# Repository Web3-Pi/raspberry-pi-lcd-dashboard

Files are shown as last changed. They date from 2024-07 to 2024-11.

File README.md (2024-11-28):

# LCD Dashboard for Raspberry Pi SBCs

<p align="center">
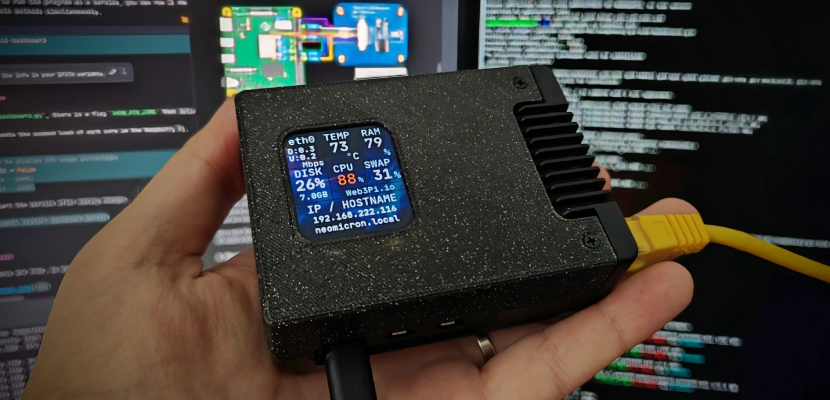
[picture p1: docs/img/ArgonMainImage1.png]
  
</p>

<p align="left">


</p>

***Unique hardware dashboard for Raspberry Pi 4 and Raspberry Pi 5 with 3D model for Argon Neo 5 enclosure*** 

***This repository is part of the [Web3Pi](https://www.web3pi.io) initiative, which enables the automated deployment of a full Ethereum node on a Raspberry Pi.***

This project allows you to install a color LCD display in the Argon Neo 5 case and display the following system parameters:

- CPU Usage
- CPU Temperature
- RAM Usage
- SWAP Memory Usage
- Storage Usage
- IP / Hostname
- Network Traffic (eth0/WiFi)

We have designed our own 3D model of the enclosure cover with a space for the display. The assembly is simple, using snap-fits, with no tools required. The models are open-source, so anyone can print them on a 3D printer. The source code is also open-source, allowing users to add new functionalities, customize it to their needs, or add support for new displays.

## Disclaimer

Raspberry Pi is a trademark of Raspberry Pi Ltd. The use of this trademark here is solely for descriptive purposes. I am not affiliated with Raspberry Pi Ltd. I derive no financial benefit from this content.

## Requirements

- Python >= 3.9
- Run on Raspberry Pi 4 and 5
- Raspberry Pi OS or Ubuntu
- [SPI interface enabled](docs/EnableSPI.md)
- 1.69" LCD display with ST7789V2 Driver
  - Waveshare 24382 - [product page](https://www.waveshare.com/1.69inch-lcd-module.htm)
  - Seeed Studio 104990802 - [product page](https://www.seeedstudio.com/1-69inch-240-280-Resolution-IPS-LCD-Display-Module-p-5755.html)
- (Optional) 3D printed model of Argon Neo 5 cover
- (Optional) Argon Neo 5 enclosure

## Assembly

### 1. Connect wires
Connect the display to the Raspberry Pi according to the diagram below.  
The colors of the cables may vary depending on the supplier and batch. Focus on the function and pin number, not the color.

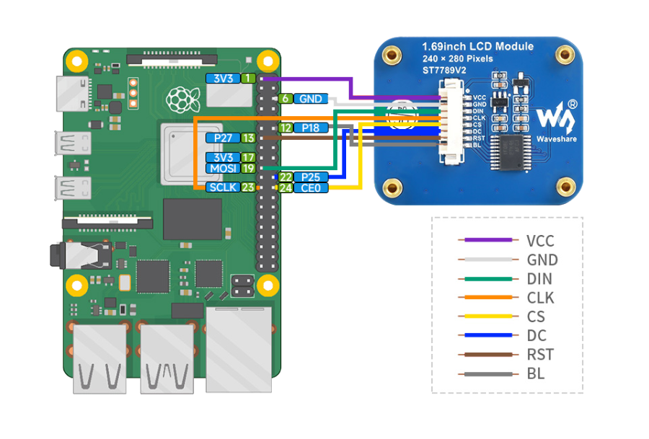
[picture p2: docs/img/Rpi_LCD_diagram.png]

Diagram is valid for Raspberry Pi 4 and Pi 5

If on Raspberry Pi 5 your LCD backlight is flickering connect `BL` to `3.3V PIN 17`

### 2. Mount display module

Mount the display in the printed enclosure cover. The display is held in place by four clips. Make sure all 3D printing support residues are removed and the surface to which the display adheres is flat. Install the display by sliding one side under the clips first, then pressing the other side down. Do not use excessive force to avoid damaging the display. The display should fit in easily.

Since each 3D printer may be calibrated differently, it may be necessary to adjust the scale of the 3D model in the slicer software before printing. Our prints are done on [Original Prusa i3 MK3S+](https://www.prusa3d.com/pl/produkt/drukarka-3d-original-prusa-i3-mk3s-3/).

### 3. Mount enclosure cover

Mount the enclosure cover and secure it with two screws. Make sure to arrange the cables inside the enclosure so they do not obstruct the fan and minimize interference with cooling.

## Installation

To enable the display, the SPI interface must be enabled.  
To do this, execute the following command and then reboot the device:

```shell
sudo sed -i '/^#dtparam=spi=on/s/^#//' /boot/firmware/config.txt
sudo reboot
```

Download the repository.

```shell
sudo apt-get -y install git
git clone https://github.com/Web3-Pi/raspberry-pi-lcd-dashboard.git
```

Then, you can run the program as a service. The program will start automatically with the system startup.  
Alternatively, you can run it once. The program will stop when you close the console.

### Run as a service - (recommended)   

```shell
cd raspberry-pi-lcd-dashboard
chmod +x *.sh
sudo ./create_service.sh
```

To **stop** the program, execute `sudo systemctl stop dashboard.service`

To **uninstall** the service, execute `sudo ./remove_service.sh`

### or run one time

If you do not want to run the program as a service, you can run it once.   
Note: Do not use both methods simultaneously.

```shell
cd raspberry-pi-lcd-dashboard
chmod +x *.sh
sudo ./run.sh
```
To stop the program, press Ctrl+C.

## Customisation

In the file `dashboard.py`, there is a flag `SHOW_PER_CORE` that determines whether the CPU usage percentage should be in the range of `0-100%` or `0-400%`.

0-400% represents the summed load of each core in the Raspberry Pi.

```python
# Choose how to display CPU usage percentages
SHOW_PER_CORE = False
# False = [0 - 100%]
# True  = [0 - 400%]
```
note: Restart the service after making changes.   
```shell
sudo systemctl restart dashboard.service
```

## 3D Model

The models are free, so anyone can print them on a 3D printer.

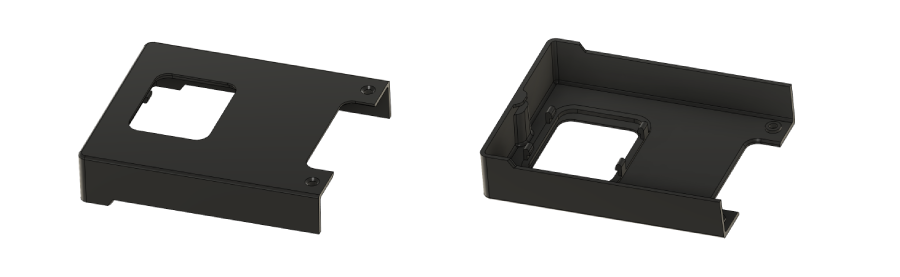
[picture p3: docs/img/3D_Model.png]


Download 3D model: [3D_Model](docs/3D_Model)

## 3D Printing

We recommend printing with [PETG](https://botland.store/849-petg-filaments?manufacturers=devil-design,prusa&weight=1000-g&material=petg&diameter=1-75-mm) filament due to the high operating temperatures of the Raspberry Pi.  
To ensure the snap-fits print correctly, enable 'supports everywhere.'  
Use a 0.4 mm nozzle.  
0.2 mm layer height or smaller.  
Our models are printed on [Original Prusa i3 MK3S+](https://www.prusa3d.com/pl/produkt/drukarka-3d-original-prusa-i3-mk3s-3/)

If you do not have access to a 3D printer, you can order an online print from one of the providers such as [JLC3DP](https://jlc3dp.com/3d-printing-quote).   
There are various materials technology and you can choose from:
- FDM - ABS, ASA or PA12-CF
- MJF - PA16-HP Nylon
- SLS - 3201PA-F Nylon

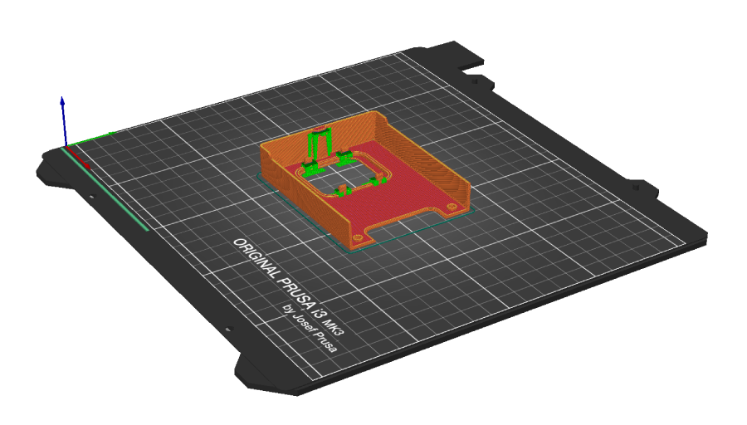
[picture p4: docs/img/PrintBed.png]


## Contribution

Are you passionate about open-source development? We invite you to contribute to our GitHub repository! Whether you're a seasoned developer or just starting out, your ideas, code, and feedback are invaluable. Join our community, collaborate with like-minded individuals, and help us build something amazing together. Every contribution, no matter how small, makes a difference. Fork the repo, dive into the issues, and let's make this project even better!

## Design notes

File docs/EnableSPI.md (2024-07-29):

# Enable SPI Interface

* Open the terminal, use the command to enter the configuration page:

```
sudo apt-get install raspi-config
sudo raspi-config
```

Choose Interfacing Options -> SPI -> Yes  to enable SPI interface

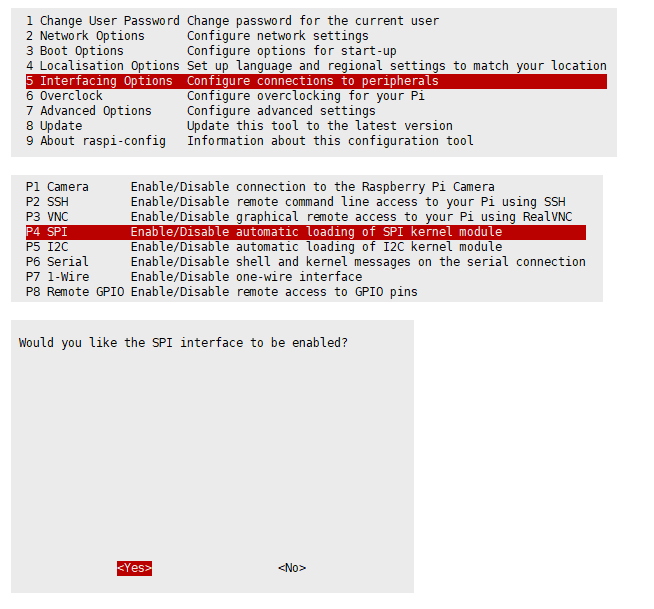
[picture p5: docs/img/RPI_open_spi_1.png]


Reboot Raspberry Pi：

```
sudo reboot
```

* Check /boot/config.txt and you can see that 'dtparam=spi=on' has been written.



* To make sure that the SPI is not occupied, it is recommended that other driver overrides be turned off for now. You can use ls /dev/spi* to check the SPI occupancy. The terminal output /dev/spidev0.0 and /dev/spidev0.1 indicates that the SPI status is normal.



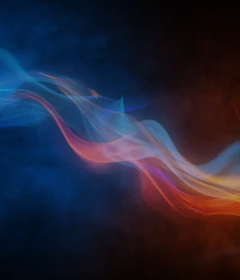
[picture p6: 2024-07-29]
img/lcdbg2.png

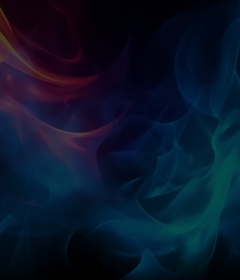
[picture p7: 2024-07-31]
img/lcdbg1.png

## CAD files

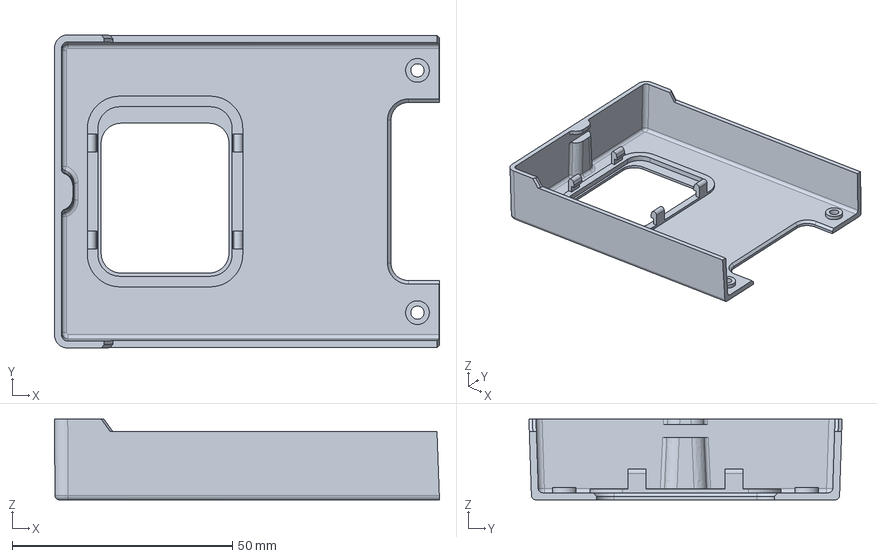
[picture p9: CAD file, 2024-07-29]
docs/3D_Model/Argon_Neo_5_Top_LCD.step
87.4 x 71.1 x 18.3 mm

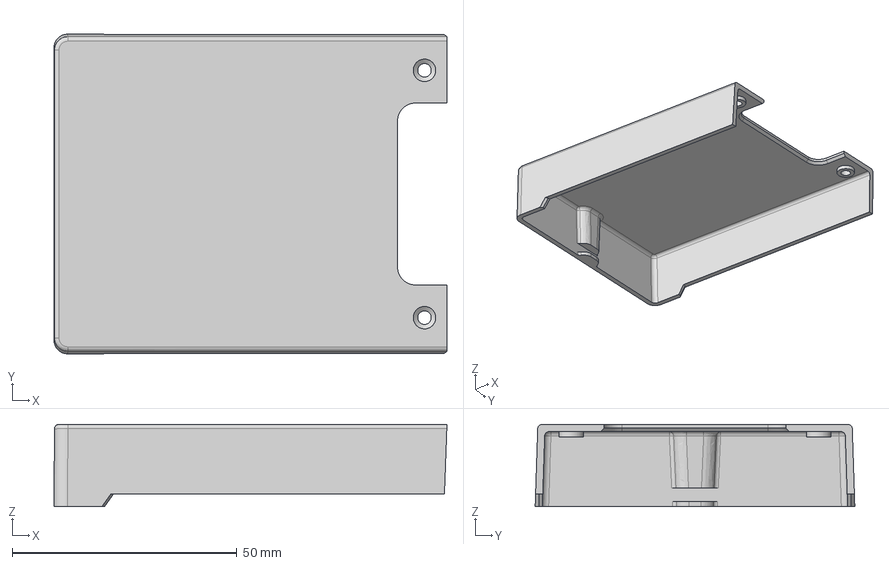
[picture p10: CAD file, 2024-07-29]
docs/3D_Model/ArgonNeo5Top.step
87.4 x 71.1 x 18.3 mm

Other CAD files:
docs/3D_Model/ArgonNeo5Top.3mf
docs/3D_Model/ArgonNeo5Top.stl
docs/3D_Model/Argon_Neo_5_Top_LCD.3mf
docs/3D_Model/Argon_Neo_5_Top_LCD.stl

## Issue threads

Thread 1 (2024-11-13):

Some questions and one issue

araeubig, 2024-11-13:
First i have to say: Your idea and solution is absolutely great and since 1 hour the Waveshare Display is running fine (based on your great installation help / documentation). Thanks for that.

One issue: By shutting down the RasPi the display stays alive. How could i power off the display when shutting down the raspberry?

Some questions:
- i read in the config files that it would be possible to use the display in landscape format. Do you have some hints for me to get this working?
- my goal is to use the same display with touch option (the Waveshare model too) and let the display go off after some minutes and to reactivate by touching it. Therefore it would be nice to get some hints too. At the end the touch should activate the display first and with a second touch i want to display a small menu (HOME (like it is actual the stats screen, HOME2 (with other stats data from influx), SHUTDOWN and REBOOT

The whole setup should be placed in a DIN/REG case and based on your STEP-files i will make a new "front-cover" for the Waveshare DIN case.

I think i could make a fork of your repo and add the new created files or i could send you all files for your repo if they are ready.

Regards André

cmd0s, 2024-11-28:
Hello André,

I'm really glad to hear that my project has been helpful and that your Waveshare Display is running smoothly with the installation guide.

Regarding your questions:

1. **Landscape orientation**: Unfortunately, this cannot be easily configured through a standard config file. It requires modifying the source code to adjust for the orientation. The good news is that it’s absolutely doable and not overly complicated if you’re familiar with basic coding.

2. **Forking the repository**: Feel free to fork my repository! It’s under a very open license, so you’re welcome to modify the code as needed. If you want, you can share your updates or improvements as a pull request, but it’s entirely up to you.

3. **PWM for brightness control**: PWM (used for controlling the brightness) is a tricky topic on the Raspberry Pi 5. That’s why, in my implementation, the brightness is fixed at 100%. If someone manages to come up with a reliable solution for this, I’d be more than happy to incorporate it into the repository.

Best regards,
Robert

cmd0s, 2024-11-28:
> One issue: By shutting down the RasPi the display stays alive. How could i power off the display when shutting down the raspberry?
>

I've added some code, and now the program detects when the application is shutting down. Before closing, it clears the screen and cleans up SPI interface.

I hope this is what you were looking for! 😊

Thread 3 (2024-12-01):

Request

jameskeim, 2024-12-01:
Reading through the configuration files, I can't see a way to flip the text/graphical output 180 degrees. Initially I thought I could insert the LCD the other direction to flip the screen but now that I have it in hand, I can see the case was made to fit the screen in one direction. Ideally, if the case is sitting on my desk, I'd like the power cable and any HDMI cables to exit above the screen rather than below it. Seems like a minor issue but I'm trying to reduce cable clutter. Is it possible to rewrite the X,Y screen initialization code to flip the screen?

Otherwise, brilliant design that allows me to see the system's status at a glance.

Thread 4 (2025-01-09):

Landscape Mode + Touch (Waveshare 27057)

MGPhil, 2025-01-09:
Thanks for the script and great work,
as in my setup I can only use the display in landscape
is there a parameter or easy way to rotate your gui 90°?

Additionally I have seen that waveshare display (https://www.waveshare.com/1.69inch-touch-lcd-module.htm)
which has the same resolution and driver IC
but integrates touch as well.
Any chance that you implement touch features into your great script?

Thanks

cmd0s, 2025-01-10:
Thank you for your kind words and feedback!

As for the Waveshare display with touch integration, I actually plan to support this display in the future. While the display itself uses the same driver IC, implementing touch functionality would require additional work to handle the touch input.

I don’t anticipate releasing support for it sooner than in 3 months because my hands are currently full with other tasks. Additionally, this touchscreen display is likely to be part of my next project, during which I plan to add support for it as part of that development effort.

Thank you for your patience and for sharing your thoughts! 😊

MGPhil, 2025-01-11:
Great then I choose the right display for my project ;-),
only thing is that I would need at least landscape screen with same displayed parameters
within the next 1 max 2 weeks.
Touch could come later.

Any advise or better chance that you squeeze that in your work schedule?
Thanks a lot!

cmd0s, 2025-01-11:
Could you share a bit more about the project you’re working on? It sounds intriguing!

MGPhil, 2025-01-11:
Sure, I am working on a 19 inch rack mount 1U status monitor for 8 raspberry pi 5.
CAD is ready, will mill the rack panel and assembly the displays in it in the next days.
It will look like this:
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

cmd0s, 2025-01-11:
I really like your project! Funny enough, a few months ago, I started designing something very similar, but I didn’t get the chance to finish it. And just 30 minutes ago, I installed a 19" rack setup for 4x Raspberry Pi 5, each with an M.2 NVMe slot for storage ([DR-0001](https://wiki.52pi.com/index.php?title=DR-0001) model from 52Pi.com).

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

I’ll try to help you with rotating that image by 90 degrees soon.
By the way, in your setup, will the Raspberry Pi boards also have M.2 NVMe storage support?

Looking forward to hearing more about it!

MGPhil, 2025-01-11:
Yes I have 2 1U Racks were I am installing the 8x Raspberry Pi 5 today
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
https://racknex.com/raspberry-pi-rackmount-kit-4x-slot-19-inch-um-sbc-209/

I am using using a HAT for POE+ Power (5V 5A) and SSD support:
https://www.welectron.com/Pineboards-TM1L-POE-HatDrive-POE-fuer-Raspberry-Pi-5
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

The 1U 8 displays will sit in between the 2 times 4 raspberry pis
and should enable to see the PI status at a glance when I walk by the rack.

cmd0s, 2025-01-11:
Cool! I have two questions that come to mind:

1. What’s your intended use case for a Raspberry Pi 5 cluster with NVMe?
2. How are you planning to connect the displays to the Raspberry Pi boards? With the adapter you showed, the GPIO header pins don’t extend above the connector. You’d need to use some kind of extension for those pins and then extend the connections to reach the displays, even when the rack with the Raspberry Pi boards is pulled out.

MGPhil, 2025-01-11:
Use case is a cluster server with lots of data management, security and redundancy.

Connection the displays and rack leds/button will probably be soldered directly
to the SMD pin of the 40pin header from the POE hat.
Making the pins longer would not fit the 1U hight limit. Not nice but will work.

For being able to pull out the rack and take it to repair place if needed I use cables with connectors (with lock notch)
and solder one side on the poe hat and the other side on the included cable from the display
to not have to disconnect the small pcba connector an the tiny waveshare screens every time.

Something like that with the right pin amount or maybe 2 cables, one for touch for one display connection for each display.
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

MGPhil, 2025-01-23:
Made some progress, HW is installed, cabling tomorrow evening, then I would need rotated software please ;-)

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

Pinout I would suggest following (should match your SW as it is right now + touch, DRV8830 for external FAN control and Status LEDs in the rack):
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

cmd0s, 2025-01-23:
The version for horizontally oriented displays is available in the `landscape-mode` branch.
Link: https://github.com/Web3-Pi/rpi-lcd-dashboard/tree/landscape-mode

Send a photo once the displays are up and running! 😊

MGPhil, 2025-01-24:
Hi, I tried installing it regarding the guideline but get an error when i use sudo ./run.sh
with sudo ./create_service.sh no error but also no screen. (just stays black)
What do I make wrong? Thanks

Error Log;
```
*@*:~/raspberry-pi-lcd-dashboard $ sudo ./run.sh
The script you are running has:
basename: [run.sh]
dirname : [.]
pwd     : [/home/*/raspberry-pi-lcd-dashboard]
Reading package lists... Done
Building dependency tree... Done
Reading state information... Done
python3-venv is already the newest version (3.11.2-1+b1).
The following additional packages will be installed:
  javascript-common libexpat1-dev libjs-jquery libjs-sphinxdoc libjs-underscore libpython3-dev libpython3.11-dev python3-dev python3-setuptools
  python3-wheel python3.11-dev zlib1g-dev
Suggested packages:
  apache2 | lighttpd | httpd python-setuptools-doc
The following NEW packages will be installed:
  javascript-common libexpat1-dev libjs-jquery libjs-sphinxdoc libjs-underscore libpython3-dev libpython3.11-dev python3-dev python3-pip python3-setuptools
  python3-wheel python3.11-dev zlib1g-dev
0 upgraded, 13 newly installed, 0 to remove and 0 not upgraded.
Need to get 4,394 kB/8,580 kB of archives.
After this operation, 38.3 MB of additional disk space will be used.
Err:1 http://deb.debian.org/debian bookworm/main arm64 libpython3.11-dev arm64 3.11.2-6+deb12u4
  404  Not Found [IP: 199.232.18.132 80]
E: Failed to fetch http://deb.debian.org/debian/pool/main/p/python3.11/libpython3.11-dev_3.11.2-6%2bdeb12u4_arm64.deb  404  Not Found [IP: 199.232.18.132 80]
E: Unable to fetch some archives, maybe run apt-get update or try with --fix-missing?
Installing required packages...
Looking in indexes: https://pypi.org/simple, https://www.piwheels.org/simple
Collecting psutil
  Using cached psutil-6.1.1-cp36-abi3-manylinux_2_17_aarch64.manylinux2014_aarch64.whl (289 kB)
Collecting lgpio
  Using cached lgpio-0.2.2.0-cp311-cp311-manylinux_2_34_aarch64.whl (364 kB)
Collecting pillow
  Using cached pillow-11.1.0-cp311-cp311-manylinux_2_28_aarch64.whl (4.4 MB)
Collecting numpy
  Using cached numpy-2.2.2-cp311-cp311-manylinux_2_17_aarch64.manylinux2014_aarch64.whl (14.3 MB)
Collecting spidev
  Using cached spidev-3.6.tar.gz (11 kB)
  Installing build dependencies ... done
  Getting requirements to build wheel ... done
  Preparing metadata (pyproject.toml) ... done
Collecting gpiozero
  Using cached https://www.piwheels.org/simple/gpiozero/gpiozero-2.0.1-py3-none-any.whl (150 kB)
Collecting netifaces
  Using cached netifaces-0.11.0.tar.gz (30 kB)
  Preparing metadata (setup.py) ... done
Collecting colorzero
  Using cached https://www.piwheels.org/simple/colorzero/colorzero-2.0-py2.py3-none-any.whl (26 kB)
Requirement already satisfied: setuptools in ./venv/lib/python3.11/site-packages (from colorzero->gpiozero->-r requirements.txt (line 6)) (66.1.1)
Building wheels for collected packages: spidev
  Building wheel for spidev (pyproject.toml) ... error
  error: subprocess-exited-with-error

  × Building wheel for spidev (pyproject.toml) did not run successfully.
  │ exit code: 1
  ╰─> [26 lines of output]
      /tmp/pip-build-env-z0hyln7o/overlay/lib/python3.11/site-packages/setuptools/dist.py:493: SetuptoolsDeprecationWarning: Invalid dash-separated options
      !!

              ********************************************************************************
              Usage of dash-separated 'description-file' will not be supported in future
              versions. Please use the underscore name 'description_file' instead.

              By 2025-Mar-03, you need to update your project and remove deprecated calls
              or your builds will no longer be supported.

              See https://setuptools.pypa.io/en/latest/userguide/declarative_config.html for details.
              ********************************************************************************

      !!
        opt = self.warn_dash_deprecation(opt, section)
      running bdist_wheel
      running build
      running build_ext
      building 'spidev' extension
      creating build/temp.linux-aarch64-cpython-311
      aarch64-linux-gnu-gcc -Wsign-compare -DNDEBUG -g -fwrapv -O2 -Wall -g -fstack-protector-strong -Wformat -Werror=format-security -g -fwrapv -O2 -fPIC -I/home/*/raspberry-pi-lcd-dashboard/venv/include -I/usr/include/python3.11 -c spidev_module.c -o build/temp.linux-aarch64-cpython-311/spidev_module.o
      spidev_module.c:28:10: fatal error: Python.h: No such file or directory
         28 | #include <Python.h>
            |          ^~~~~~~~~~
      compilation terminated.
      error: command '/usr/bin/aarch64-linux-gnu-gcc' failed with exit code 1
      [end of output]
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
cmd0s, 2025-01-24:
Try:
`sudo apt install python3-dev python3-pip python3-venv python3.11-dev -y`

MGPhil, 2025-01-24:
Got it working now an one test unit on my table
=> Tomorrow all 8 rack ones will be running
Thanks a lot

cmd0s, 2025-01-29:
> Got it working now on one test raspberry on my table => Tomorrow all 8 rack ones will be running Thanks a lot

How's it going? Any progress?

MGPhil, 2025-02-03:
Hi, sry for the late reply, was sick the last days, influenca or some similar ugly thing...
Also had to change to another SSD and cabeling as the ones I planned does not fit inside the 1U rack slot.

Got all in the rack now and first of 8 is running so I expect the others to be up in the next hour.

Just one strange behavior when i start it either with single run or with service it works perfectly.
When I have it run as service and reboot the pi 5 via the HW button then display shows startup screen

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

but after that image goes black, any idea what that can be?

MGPhil, 2025-02-03:
Got all 8 displays working, one cable were broken internally under the isolation…good quality inspection from supplier….
Next step would be auto restart which does not work, I dont know why,
then touch support and DRV8830 for external fan control.
Thanks a lot for your support, if i can help let me know

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

cmd0s, 2025-02-04:
Your setup looks really cool. Good job!
I'll check if I also encounter the issue after a reset.
This week is quite intense at work for me, but I'll try to look into it within the next few days.

MGPhil, 2025-02-05:
Thanks, quite some work in regards of the cabling inside…
Also last display started flickering today, disassembled everything, red 3V3 supply cable internally broken…
Had now multiple cables which were not ok from factory so recommend everybody to measure these before using.
Even the more expensive ones I bought seem to be not reliable…

However lets come back to the fun part,
I will try to add DRV8830 support directly in our script so that based on the CPU temp the speed of the external fan is adjusted.
I use that board which I mounted inside the rack at the back with the fan behind the pi.
Or course one drv and one fan for each pi.
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
https://www.digikey.at/de/products/detail/seeed-technology-co-ltd/105020010/9369921
Keep you posted

MGPhil, 2025-02-10:
have not done many branches and pull requests, tried one for the DRV8830 I2C fan support, hope I made it correct?

MGPhil, 2025-04-27:
> Your setup looks really cool. Good job! I'll check if I also encounter the issue after a reset. This week is quite intense at work for me, but I'll try to look into it within the next few days.

Do you had time to check the issue?
Thanks

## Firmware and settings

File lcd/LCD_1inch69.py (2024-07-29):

import time
from . import lcdconfig


class LCD_1inch69(lcdconfig.RaspberryPi):
    width = 240
    height = 280

    def command(self, cmd):
        self.digital_write(self.DC_PIN, False)
        self.spi_writebyte([cmd])

    def data(self, val):
        self.digital_write(self.DC_PIN, True)
        self.spi_writebyte([val])

    def reset(self):
        """Reset the display"""
        self.digital_write(self.RST_PIN, True)
        time.sleep(0.01)
        self.digital_write(self.RST_PIN, False)
        time.sleep(0.01)
        self.digital_write(self.RST_PIN, True)
        time.sleep(0.01)

    def Init(self):
        """Initialize dispaly"""
        self.module_init()
        self.reset()

        self.command(0x36)
        self.data(0x00)

        self.command(0x3A)
        self.data(0x05)

        self.command(0xB2)
        self.data(0x0B)
        self.data(0x0B)
        self.data(0x00)
        self.data(0x33)
        self.data(0x35)

        self.command(0xB7)
        self.data(0x11)

        self.command(0xBB)
        self.data(0x35)

        self.command(0xC0)
        self.data(0x2C)

        self.command(0xC2)
        self.data(0x01)

        self.command(0xC3)
        self.data(0x0D)

        self.command(0xC4)
        self.data(0x20)  # VDV, 0x20: 0V

        self.command(0xC6)
        self.data(0x13)  # 0x13: 60Hz

        self.command(0xD0)
        self.data(0xA4)
        self.data(0xA1)

        self.command(0xD6)
        self.data(0xA1)

        self.command(0xE0)
        self.data(0xF0)
        self.data(0x06)
        self.data(0x0B)
        self.data(0x0A)
        self.data(0x09)
        self.data(0x26)
        self.data(0x29)
        self.data(0x33)
        self.data(0x41)
        self.data(0x18)
        self.data(0x16)
        self.data(0x15)
        self.data(0x29)
        self.data(0x2D)

        self.command(0xE1)
        self.data(0xF0)
        self.data(0x04)
        self.data(0x08)
        self.data(0x08)
        self.data(0x07)
        self.data(0x03)
        self.data(0x28)
        self.data(0x32)
        self.data(0x40)
        self.data(0x3B)
        self.data(0x19)
        self.data(0x18)
        self.data(0x2A)
        self.data(0x2E)

        self.command(0xE4)
        self.data(0x25)
        self.data(0x00)
        self.data(0x00)

        self.command(0x21)

        self.command(0x11)

        time.sleep(0.1)

        self.command(0x29)

    def SetWindows(self, Xstart, Ystart, Xend, Yend, horizontal=0):
        if horizontal:
            # set the X coordinates
            self.command(0x2A)
            self.data(Xstart + 20 >> 8)  # Set the horizontal starting point to the high octet
            self.data(Xstart + 20 & 0xff)  # Set the horizontal starting point to the low octet
            self.data(Xend + 20 - 1 >> 8)  # Set the horizontal end to the high octet
            self.data((Xend + 20 - 1) & 0xff)  # Set the horizontal end to the low octet
            # set the Y coordinates
            self.command(0x2B)
            self.data(Ystart >> 8)
            self.data((Ystart & 0xff))
            self.data(Yend - 1 >> 8)
            self.data((Yend - 1) & 0xff)
            self.command(0x2C)
        else:
            # set the X coordinates
            self.command(0x2A)
            self.data(Xstart >> 8)  # Set the horizontal starting point to the high octet
            self.data(Xstart & 0xff)  # Set the horizontal starting point to the low octet
            self.data(Xend - 1 >> 8)  # Set the horizontal end to the high octet
            self.data((Xend - 1) & 0xff)  # Set the horizontal end to the low octet
            # set the Y coordinates
            self.command(0x2B)
            self.data(Ystart + 20 >> 8)
            self.data((Ystart + 20 & 0xff))
            self.data(Yend + 20 - 1 >> 8)
            self.data((Yend + 20 - 1) & 0xff)
            self.command(0x2C)

    def ShowImage(self, Image):
        """Set buffer to value of Python Imaging Library image."""
        """Write display buffer to physical display"""
        imwidth, imheight = Image.size
        if imwidth == self.height and imheight == self.width:
            print("Landscape screen")
            img = self.np.asarray(Image)
            pix = self.np.zeros((self.width, self.height, 2), dtype=self.np.uint8)
            # RGB888 >> RGB565
            pix[..., [0]] = self.np.add(self.np.bitwise_and(img[..., [0]], 0xF8), self.np.right_shift(img[..., [1]], 5))
            pix[..., [1]] = self.np.add(self.np.bitwise_and(self.np.left_shift(img[..., [1]], 3), 0xE0),
                                        self.np.right_shift(img[..., [2]], 3))
            pix = pix.flatten().tolist()

            self.command(0x36)
            self.data(0x70)
            self.SetWindows(0, 0, self.height, self.width, 1)
            self.digital_write(self.DC_PIN, True)
            for i in range(0, len(pix), 4096):
                self.spi_writebyte(pix[i:i + 4096])
        else:
            #print("Portrait screen")
            img = self.np.asarray(Image)
            pix = self.np.zeros((imheight, imwidth, 2), dtype=self.np.uint8)

            pix[..., [0]] = self.np.add(self.np.bitwise_and(img[..., [0]], 0xF8), self.np.right_shift(img[..., [1]], 5))
            pix[..., [1]] = self.np.add(self.np.bitwise_and(self.np.left_shift(img[..., [1]], 3), 0xE0),
                                        self.np.right_shift(img[..., [2]], 3))
            pix = pix.flatten().tolist()

            self.command(0x36)
            self.data(0x00)
            self.SetWindows(0, 0, self.width, self.height, 0)
            self.digital_write(self.DC_PIN, True)
        for i in range(0, len(pix), 4096):
            self.spi_writebyte(pix[i: i + 4096])

    def clear(self):
        """Clear contents of image buffer"""
        _buffer = [0xff] * (self.width * self.height * 2)
        self.SetWindows(0, 0, self.width, self.height)
        self.digital_write(self.DC_PIN, True)
        for i in range(0, len(_buffer), 4096):
            self.spi_writebyte(_buffer[i: i + 4096])

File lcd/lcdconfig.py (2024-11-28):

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

import os
import sys
import time
import spidev
import logging
import numpy as np
from gpiozero import DigitalOutputDevice, PWMOutputDevice, DigitalInputDevice
from gpiozero.pins.lgpio import LGPIOFactory
factory = LGPIOFactory()


class RaspberryPi:
    def __init__(self, spi=spidev.SpiDev(0, 0), spi_freq=40000000, rst=27, dc=25, bl=18, bl_freq=1000, i2c=None,
                 i2c_freq=100000):
        self.np = np
        self.INPUT = False
        self.OUTPUT = True

        self.SPEED = spi_freq
        self.BL_freq = bl_freq

        self.RST_PIN = self.gpio_mode(rst, self.OUTPUT)
        self.DC_PIN = self.gpio_mode(dc, self.OUTPUT)
        self.BL_PIN = self.gpio_pwm(bl)
        self.bl_DutyCycle(0)

        # Initialize SPI
        self.SPI = spi
        if self.SPI != None:
            self.SPI.max_speed_hz = spi_freq
            self.SPI.mode = 0b00

    def gpio_mode(self, Pin, Mode, pull_up=None, active_state=True):
        if Mode:
            return DigitalOutputDevice(Pin, active_high=True, initial_value=False, pin_factory=factory)
        else:
            return DigitalInputDevice(Pin, pull_up=pull_up, active_state=active_state, pin_factory=factory)

    def digital_write(self, Pin, value):
        if value:
            Pin.on()
        else:
            Pin.off()

    def digital_read(self, Pin):
        return Pin.value

    def delay_ms(self, delaytime):
        time.sleep(delaytime / 1000.0)

    def gpio_pwm(self, Pin):
        return PWMOutputDevice(Pin, frequency=self.BL_freq, pin_factory=factory)

    def spi_writebyte(self, data):
        if self.SPI != None:
            self.SPI.writebytes(data)

    def bl_DutyCycle(self, duty):
        self.BL_PIN.value = duty / 100

    def bl_Frequency(self, freq):  # Hz
        self.BL_PIN.frequency = freq

    def module_init(self):
        if self.SPI != None:
            self.SPI.max_speed_hz = self.SPEED
            self.SPI.mode = 0b00
        return 0

    def module_exit(self):
        logging.debug("spi end")
        if self.SPI != None:
            self.SPI.close()

        logging.debug("gpio cleanup...")
        self.digital_write(self.RST_PIN, 1)
        self.digital_write(self.DC_PIN, 0)
        self.BL_PIN.close()
        time.sleep(0.001)


'''
if os.path.exists('/sys/bus/platform/drivers/gpiomem-bcm2835'):
    implementation = RaspberryPi()

for func in [x for x in dir(implementation) if not x.startswith('_')]:
    setattr(sys.modules[__name__], func, getattr(implementation, func))
'''

### END OF FILE ###

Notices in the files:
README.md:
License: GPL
